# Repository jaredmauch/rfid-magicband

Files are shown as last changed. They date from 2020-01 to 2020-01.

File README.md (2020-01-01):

# rfid-magicband

This repo includes the PCB layout for a ItsyBitsy M4 to Raspberry Pi Zero setup to adapt with a MFRC522 board and NeoPixel ring and Adafruit LiIon/LiPoly Backpack to provide for mobile reading of RFID devices, including things like the Magic Bands and park tickets.

You can configure on the Raspberry Pi a whitelist of the cards that are permissible to make the ring go green.

This is mostly an example and reference for others and I may update it as I refine the hardware and software over time.

Requirements:
Neopixel Ring
MFRC522
Raspberry Pi (zero - but pin compatible with any 40 pin Pi2-4)
ItsyBitsy M4 (M0 will also work)
PCB Adapter (from hardware directory, or breadboard it yourself)

Optional:
LiIon Battery/Backpack

It's recommended if you're in a theme park to turn off bluetooth, wifi, hdmi and anything else on the device that may cause power draw.  I may script something later that does this and makes installation easier.

I coded it in python3 and circuitpython because I'm not a heathen.

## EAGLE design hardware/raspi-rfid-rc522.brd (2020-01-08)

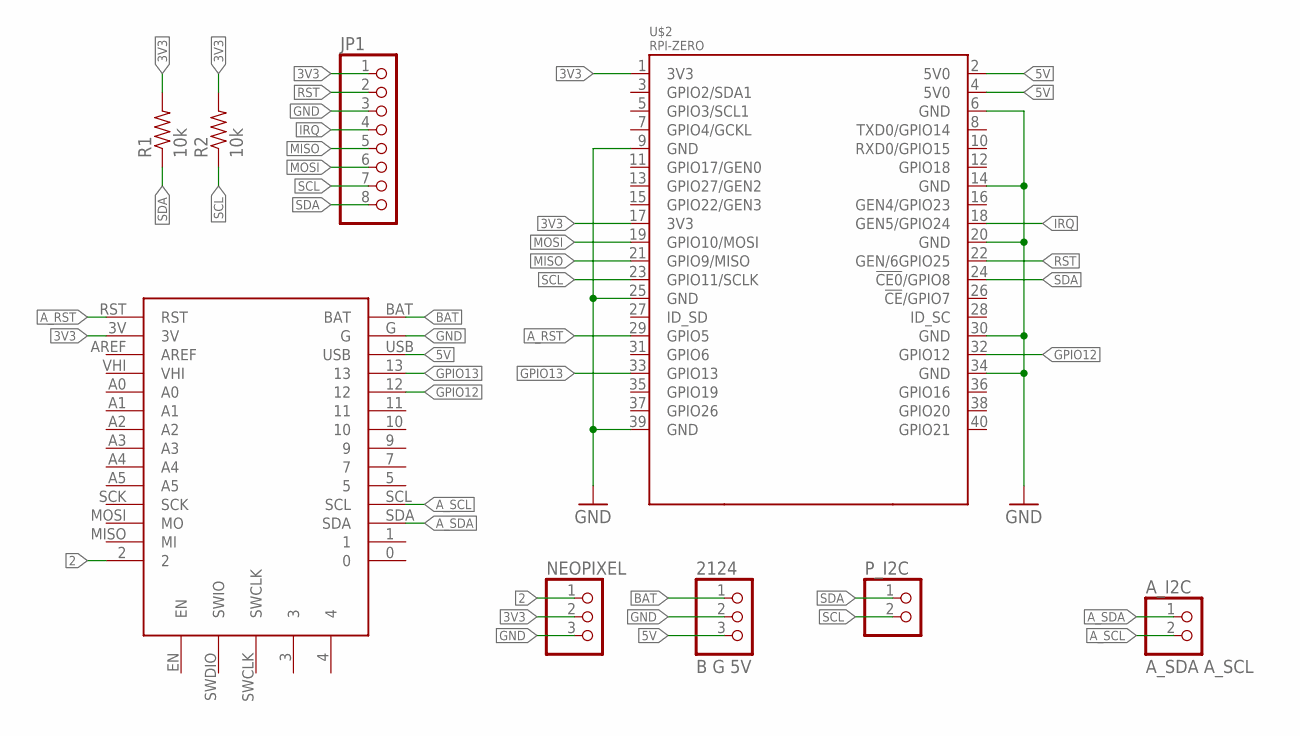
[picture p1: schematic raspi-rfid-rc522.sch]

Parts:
2124: B G 5V; 1X03
A_I2C: A_SDA A_SCL; 1X02
JP1: PINHD-1X8/90; 1X08/90
NEOPIXEL: PINHD-1X3; 1X03
P_I2C: PINHD-1X2; 1X02
R1, R2: 10k; 0603-RES
U$1: ITSYBITSYM4
U$2: RPI-ZERO; RASPBERRYPI_BASTELSTUBE_V13_RASPI_BOARD_B+_FULL

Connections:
2: NEOPIXEL.1, U$1.2
3V3: JP1.1, NEOPIXEL.2, R1.2, R2.2, U$1.3V, U$2.1 (3V3), U$2.17 (3V3)
5V: 2124.3, U$1.USB, U$2.2 (5V0), U$2.4 (5V0)
A_RST: U$1.RST, U$2.29 (GPIO5)
A_SCL: A_I2C.2, U$1.SCL
A_SDA: A_I2C.1, U$1.SDA
BAT: 2124.1, U$1.BAT
GND: 2124.2, JP1.3, NEOPIXEL.3, U$1.G, U$2.6 (GND), U$2.9 (GND), U$2.14 (GND), U$2.20 (GND), U$2.25 (GND), U$2.30 (GND), U$2.34 (GND), U$2.39 (GND)
GPIO12: U$1.12, U$2.32 (GPIO12)
GPIO13: U$1.13, U$2.33 (GPIO13)
IRQ: JP1.4, U$2.18 (GEN5/GPIO24)
MISO: JP1.5, U$2.21 (GPIO9/MISO)
MOSI: JP1.6, U$2.19 (GPIO10/MOSI)
RST: JP1.2, U$2.22 (GEN/6GPIO25)
SCL: JP1.7, P_I2C.2, R2.1, U$2.23 (GPIO11/SCLK)
SDA: JP1.8, P_I2C.1, R1.1, U$2.24 (!CE0!/GPIO8)

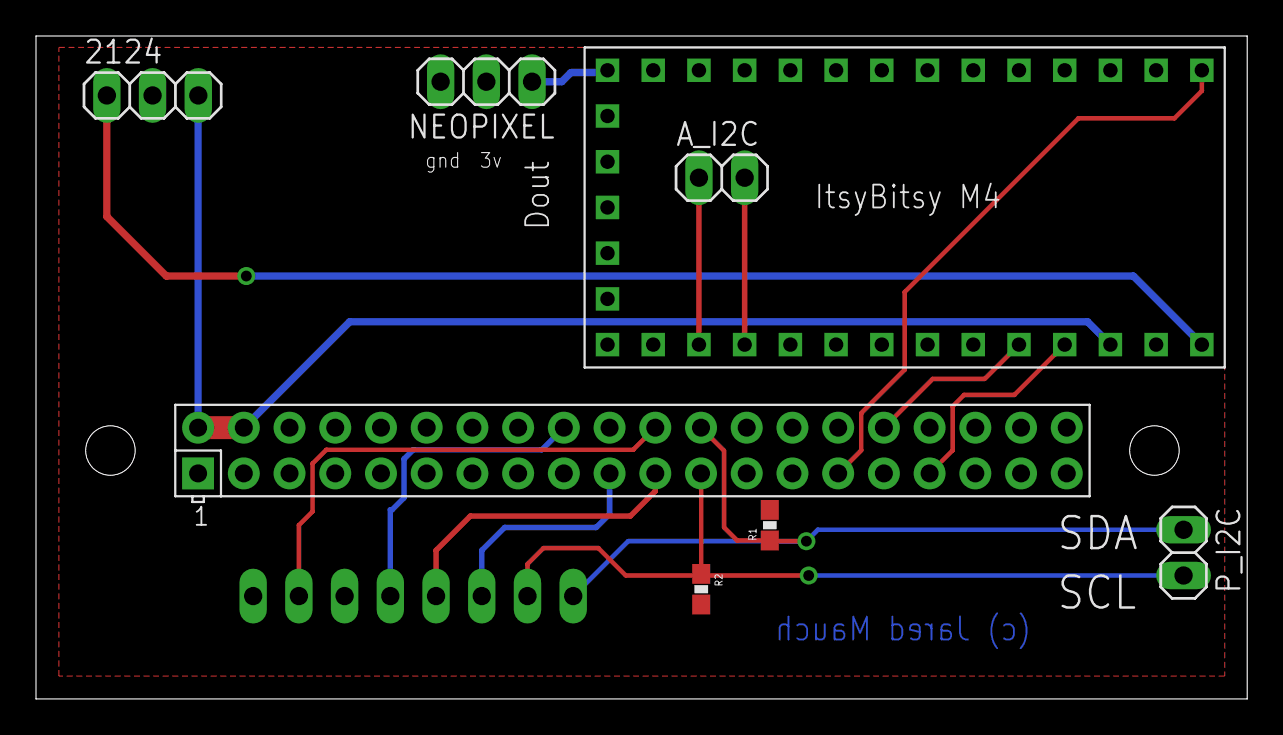
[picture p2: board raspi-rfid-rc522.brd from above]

Board: 2 copper layers, 67.3 x 36.8 mm, 9 parts (1 on the bottom side), 16 nets.

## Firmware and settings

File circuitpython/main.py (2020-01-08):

# Imports
#
# tested: circuit python 4.1.2
#
# install lib/adafruit_dotstar to /lib/ on the filesystem
# install lib/neopixel.mpy to /lib/ on the filesystem
#
# https://github.com/adafruit/Adafruit_CircuitPython_Bundle/releases
#
import time      # what time is it?
import board     # for board
import busio     # for i2c
import neopixel  # for led ring
import digitalio # for spi

import adafruit_dotstar # for on-board LED

led = adafruit_dotstar.DotStar(board.APA102_SCK, board.APA102_MOSI, 1)
led.brightness = 0.0 # turn the on-board LED off (save power)
led[0] = (0, 0, 0) # turn the on-board LED off (save power)

# i never managed to get the i2c way to work
# so strapped the pi zero instead, revisit this code?
try: 
  # i2c for the RFID-RC522
  i2c = busio.I2C(board.SCL, board.SDA)
  # Lock the I2C device before we try to scan
  while not i2c.try_lock():
      pass
  # Print the addresses found once
  print("I2C addresses found:", [hex(device_address)
                               for device_address in i2c.scan()])
  # Unlock I2C now that we're done scanning.
  i2c.unlock()
except:
  # 
  print("i2c seems to not be wired up right, check that a 10k pull up is on both SDA and SCL")
#
pixpin = board.D2  # what pin the LEDs are on
sensepin = digitalio.DigitalInOut(board.D12) # What pin the sense is on
numpix = 60  # number of LEDs in ring!
BPP = 3

ring = neopixel.NeoPixel(pixpin, numpix, bpp=BPP, brightness=0.1, auto_write=False)

half = int(numpix / 2)
quarter = int(numpix / 4)
mode = 1
sense_count = 0
while True:
    # Two lines for troubleshooting to see analog value in REPL
    ring.show()
    # slow spinning white ring
    if mode == 1:
        sense_count = 0
        print("Mode 1")
        for x in range(half-1, 0-1, -1):
#          print(x,x+half)
          ring[x] = (64,64,64)
          ring[x+half] = (64,64,64)
          ring.show()
          time.sleep(0.05)
          ring[x] = (0,0,0)
          ring[x+half] = (0,0,0)
          check_value = sensepin.value
          if check_value:
            lastpin = check_value
            mode = 2
            break

    # fast white spinning ring
    if mode == 2:
          print("Mode 2")
          print("D12 = ", sensepin.value)

          speed_range = int(numpix/3)
          for speed in range(quarter, 0, -1):
            for x in range(half-1, 0-1, -2):
              check_value = sensepin.value
              if check_value != lastpin:
                  sense_count = sense_count + 1
                  lastpin = check_value
#              print (speed, x, speed_range-speed+2, x-speed)
              ring[x] = (255,255,255)
              ring[x+half] = (255,255,255)
#              for y in range(x-speed_range-speed+2, x):
#                ring[y] = (255,255,255)
              if sense_count > 2:
                  break
              ring.show()
#              time.sleep(speed*.005)
              if (speed > 0):
                ring[x] = (0,0,0)
                ring[x+half] = (0,0,0)
#                for y in range(x-speed_range-speed+2, x):
#                  ring[y] = (0,0,0)
          mode = 3


    # green ring
    if mode == 3:
        print("Mode 3")
        print("D12 = ", sensepin.value)
        print("sense_count =", sense_count)
        if sense_count < 2:
            ring.fill((0,255, 0))
            ring.show()
            time.sleep(3)
        else:
            for z in range (0, 3):
                # blue dimming
                for y in range (255, 0, -32):
#                    print("y = ", y)
                    ring.fill((0, 0, y))
                    ring.show()
                # blue brightening 
                for y in range (0, 255, 32):
#                    print("y = ", y)
                    ring.fill((0, 0, y))
                    ring.show()

        mode = 1
        ring.fill((0,0,0))
        ring.show()


    if mode == 4:
        print("Tiki")

        ## tiki mode
        for x in range (0, 24):
          for y in range (0, 5): 
#            print("y = ", y)
            ring[0+y*12] = ( 255, 0, 0)
            ring[1+y*12] = ( 192, 64, 0)
            ring[2+y*12] = ( 128, 128, 0)
            ring[3+y*12] = ( 128, 128, 0)
            ring[4+y*12] = ( 64, 192, 0)
            ring[5+y*12] = ( 32, 255, 0)
            ring[6+y*12] = ( 0, 255, 0)
            ring[7+y*12] = ( 0, 192, 64)
            ring[8+y*12] = ( 0, 128, 128)
            ring[9+y*12] = ( 0, 64, 128)
            ring[10+y*12] = ( 0, 64, 192)
            ring[11+y*12] = ( 0,0,255)

          ring.show()
          ring.fill((0,0,0))
          ring.show()
        mode = 1

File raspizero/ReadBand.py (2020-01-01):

#!/usr/bin/env python3

# sudo apt-get install python3-dev python3-pip python3-spidev python3-rpi.gpio
# sudo pip3 install mfrc522

# should set pin GPIO12/32 to high when we see something we like

import RPi.GPIO as GPIO
from mfrc522 import SimpleMFRC522
import time

pin_number = 32 # BCM GPIO 12 is physical pin 32

valid_bands =  [ 584197446646, 584185892850, 584186412169 ]

while True: 
    print("Waiting for a band to read")
    reader = SimpleMFRC522()
    try:
            GPIO.setup(pin_number, GPIO.OUT)
            GPIO.output(pin_number, GPIO.LOW)
            id, text = reader.read()
            GPIO.setmode(GPIO.BOARD)
            GPIO.setup(pin_number, GPIO.OUT)
            GPIO.output(pin_number, GPIO.LOW)
            print("Saw Band:", id)
            print(text)
            if id in valid_bands:
                print("Should ask ring to go immediately green!")
                GPIO.output(pin_number, GPIO.HIGH)
            else:
                GPIO.output(pin_number, GPIO.HIGH)
                time.sleep(0.2)
                GPIO.output(pin_number, GPIO.LOW)
                time.sleep(0.2)
                GPIO.output(pin_number, GPIO.HIGH)
                print("Should ask ring to go to pulsing blue")
            time.sleep(1)
            GPIO.output(pin_number, GPIO.LOW)

    finally:
        GPIO.cleanup()

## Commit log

2020-01-01 sync hardware
    [raspi-rfid-rc522.brd, raspi-rfid-rc522.sch]
2020-01-08 turn off m4 led
2020-01-08 update pcb
    [raspi-rfid-rc522.brd, raspi-rfid-rc522.sch]
